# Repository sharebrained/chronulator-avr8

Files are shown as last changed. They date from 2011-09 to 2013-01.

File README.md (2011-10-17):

chronulator-avr8
================

by ShareBrained Technology

The latest version of this repository can be found at:
<https://github.com/sharebrained/chronulator-avr8>

Description
===========

An analog panel meter clock implementation based on the
Atmel AVR8 microcontroller.

Time is displayed via two analog meters, one for hours
and one for minutes. The microcontroller keeps time via
a 32.768kHz crystal, and controls the meter needles
using pulse-width modulation of current sources.

The current sources are adjustable by variable
resistors, and the time is set by momentary buttons.

A simple set of commands are supported via the AVR8
serial port. Meter needles can be controlled directly
via commands, overriding the default time-based
control. The brightness of two LEDs can be controlled
by other commands.

Documentation
=============

See http://www.sharebrained.com/chronulator/ for
hardware documentation.

Requirements
============

Software
--------

* Arduino IDE (to program the Chronulator firmware)
* avrdude (to program the AVR8 bootloader)
* avr-gcc (to compile and link the bootloader)
* EAGLE 5.x (to edit the schematic or circuit board)

Hardware
--------

* A Chronulator or Chronulator-compatible device.
* A serial adaptor and/or an Atmel ISP programmer.

Usage
=====

Before compiling and uploading this code in the Arduino
IDE, please select "LilyPad Arduino w/ ATmega168" under
the "Tools->Board" menu.

Contact
=======

ShareBrained Technology, Inc.
<http://www.sharebrained.com/>

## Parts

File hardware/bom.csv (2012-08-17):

Ref Des | Description | Package | Manufacturer | Manufacturer Part | Supplier | Supplier Part | Qty
U1 | IC AVR MCU 16K 10MHZ 28DIP | 28-DIP | AVR | ATMEGA168V-10PU | Digi-Key | ATMEGA168V-10PU-ND | 1
R1,2,5,6,7 | RES 10K OHM 1/4W 5% CARBON FILM | Axial | Yageo | CFR-25JB-10K | Digi-Key | 10KQBK-ND | 5
R3,8 | RES 82K OHM 1/4W 5% CARBON FILM | Axial | Yageo | CFR-25JB-82K | Digi-Key | 82KQBK-ND | 2
R4,9 | POT 5K OHM 9MM HORZ NO BUSHING | 9mm | Panasonic | EVU-E3AF25B53 | Digi-Key | P3M3502-ND | 2
Q1,2,3,4 | IC TRANS PNP SS GP 200MA | TO-92 | Fairchild | 2N3906BU | Digi-Key | 2N3906FS-ND | 4
C1,2 | CAP 18PF 50V CERAMIC C0G 5% | Radial, 5.08mm, orange | Vishay/BC | K180J15C0GF5TH5 | Digi-Key | BC1033CT-ND | 2
C3,4,6 | CAP CER 100000PF 50V Y5V | Radial, 5.0mm blue | Murata | RPEF51H104Z2K1A03B | Digi-Key | 490-3859-ND | 3
C5 | CAP CER 10UF 10V Y5V RAD | Radial, 5.0mm, blue, short leads | TDK | FK24Y5V1A106Z | Digi-Key | 445-2868-ND | 1
S1,2,3 | SWITCH TACT 6MM SPST PCB H=7.3MM | 6mm | ITT/C&K | PTS645SJL73 LFS | Digi-Key | CKN9072-ND | 3
X1 | CRYSTAL 32.768KHZ 12.5PF CYL | Abracon | AB38T-32.768KHZ | Digi-Key | 535-9034-ND | 1
 | HOLDER BATT 2-AA CELLS WIRE LDS | 2xAA | MPD | BC22AAW | Digi-Key | BC22AAW-ND | 1
BAT | CONN PWR JACK RT ANG 1.3MM I.D. |  | CUI | PJ-007 | Digi-Key | CP-2519-ND | 1
 | CONN POWER PLUG 3.5MM X 1.3MM |  | CUI | PP3-002D | Digi-Key | CP3-1003-ND | 1
H,M | 100uA panel meter |  | GME | PM89 100uA | GME | PM89-D100UA | 2
 | PCB |  | Advanced Circuits |  |  | pm2v-2.01 | 1
BAT/USB | CONN HEADER 50POS .100" SGL GOLD |  | Samtec | TSW-150-07-L-S | Digi-Key | SAM1031-50-ND
JUMPER | CONN JUMPER SHORTING GOLD FLASH |  | Sullins | SPC02SYAN | Digi-Key | S9001-ND | 1
SERIAL | CONN HDR 50POS .100" SNGL R/A |  | Samtec | TSW-150-08-T-S-RA | Digi-Key | SAM1051-50-ND
R10,11 | RES 0 OHM 1/4W 5% CARBON FILM | Axial | Stackpole | CD 1/4 0 R | Digi-Key | CD1/40RCT-ND | 2
D1,2,3,4,5 | LED 5MM COOL WHITE CLEAR 110DEG | Radial | Cree | C535A-WJN-CU0V0231 | Digi-Key | C535A-WJN-CU0V0231-ND | 2
ISP | CONN HDR BRKWAY .100 80POS VERT |  | Tyco | 4-103777-0 | Digi-Key | A26525-40-ND

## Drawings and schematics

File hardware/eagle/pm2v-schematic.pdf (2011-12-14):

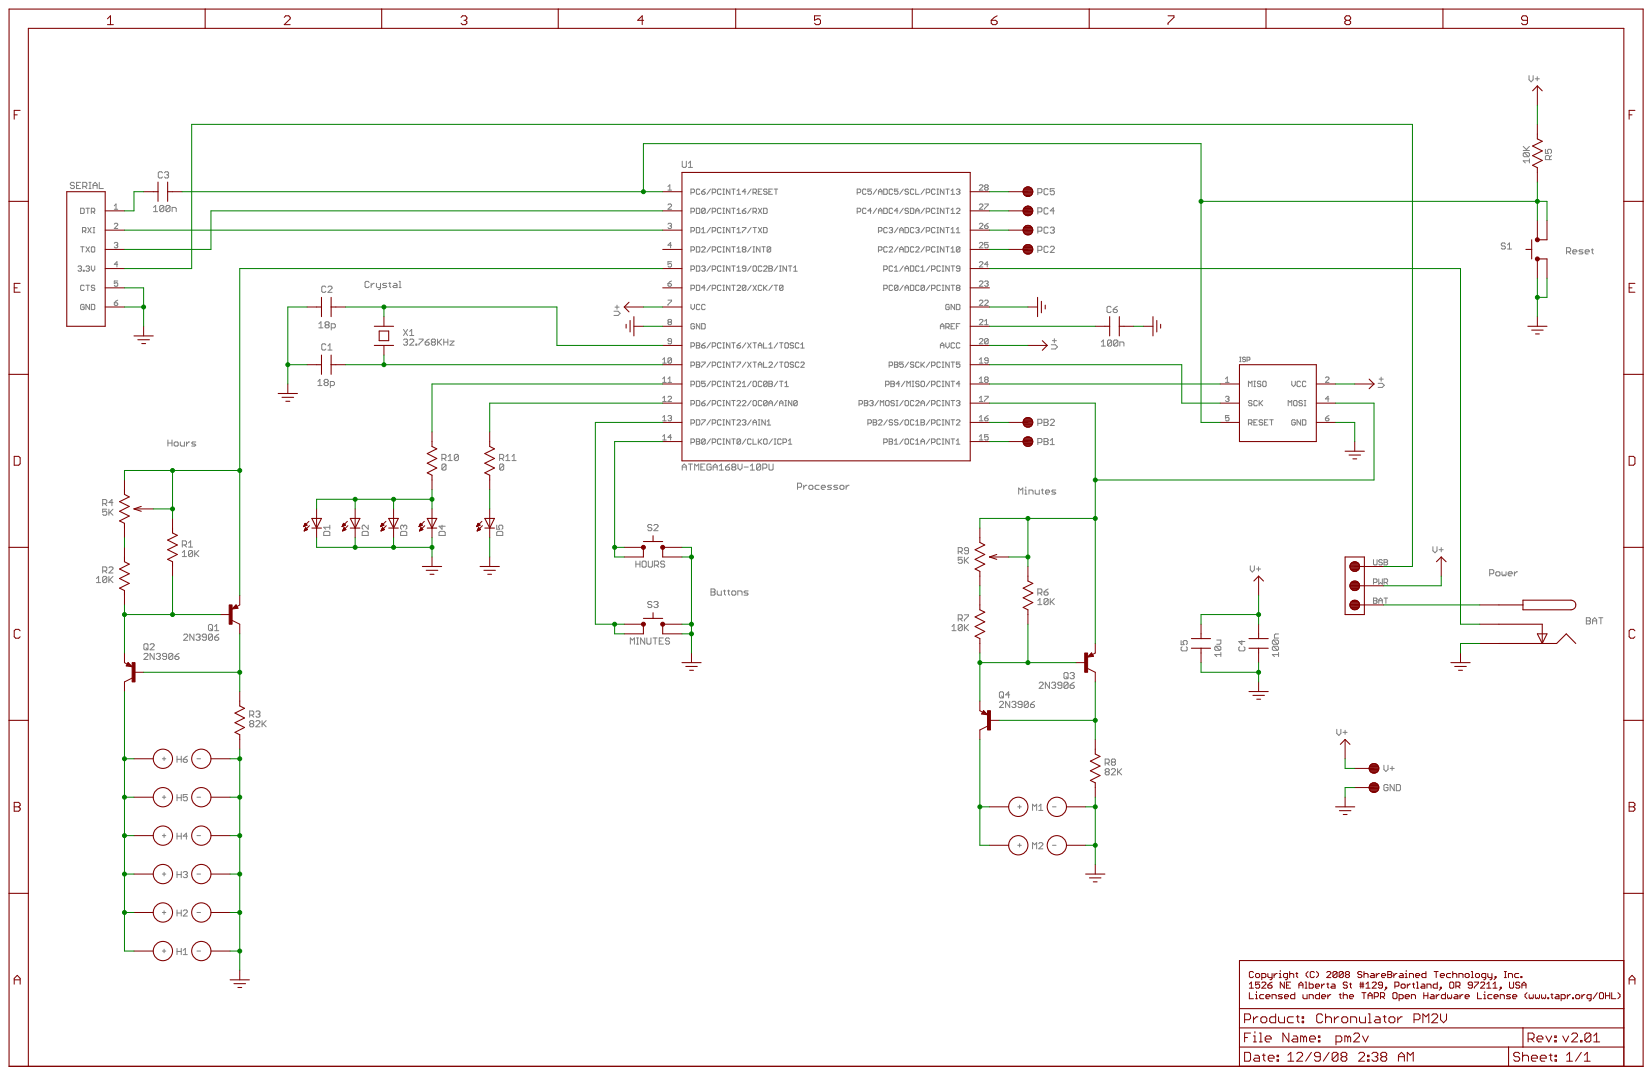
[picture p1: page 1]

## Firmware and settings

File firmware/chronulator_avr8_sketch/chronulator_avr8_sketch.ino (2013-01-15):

/*
 **********************************************************
 *
 * Copyright 2008-2013 ShareBrained Technology, Inc.
 *
 * This file is part of chronulator-avr8.
 *
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
 **********************************************************
 */

#include <avr/sleep.h>
#include <avr/power.h>
#include <util/delay.h>

#include "chronulator_types.h"

#define VERSION_RELEASE "201301151246-alpha"
#define F_CPU 4000000

static const unsigned short update_tick_interval = (1 << 4);

static const unsigned short servo_cycle_time = 20000;

static const unsigned short servo_center_minutes = 1500;
static const unsigned short servo_center_hours = 1500;

static const unsigned short servo_range_minutes = 900;
static const unsigned short servo_range_hours = 900;

static const unsigned char servo_h_power_timeout = 128 / update_tick_interval;
static const unsigned char servo_m_power_timeout = 128 / update_tick_interval;

static const unsigned char debounce_wait = 8;

#define HOURS_BUTTON_PIN (PINB)
#define HOURS_BUTTON_PIN_BIT (_BV(PINB0))
#define HOURS_BUTTON_PORT (PORTB)
#define HOURS_BUTTON_PORT_BIT (_BV(PORTB0))
#define HOURS_BUTTON_DDR (DDRB)
#define HOURS_BUTTON_DDR_BIT (_BV(DDB0))

#define MINUTES_BUTTON_PIN (PIND)
#define MINUTES_BUTTON_PIN_BIT (_BV(PIND7))
#define MINUTES_BUTTON_PORT (PORTD)
#define MINUTES_BUTTON_PORT_BIT (_BV(PORTD7))
#define MINUTES_BUTTON_DDR (DDRD)
#define MINUTES_BUTTON_DDR_BIT (_BV(DDD7))

#define METER_M_OCR (OCR2A)
#define METER_M_DDR (DDRB)
#define METER_M_DDR_BIT (_BV(DDB3))

#define METER_H_OCR (OCR2B)
#define METER_H_DDR (DDRD)
#define METER_H_DDR_BIT (_BV(DDD3))

#define METER_S_OCR (OCR0A)
#define METER_S_DDR (DDRD)
#define METER_S_DDR_BIT (_BV(DDD6))

#define METER_MS_OCR (OCR0B)
#define METER_MS_DDR (DDRD)
#define METER_MS_DDR_BIT (_BV(DDD5))

#define SERVO_M_OCR (OCR1A)
#define SERVO_M_DDR (DDRB)
#define SERVO_M_DDR_BIT (_BV(DDB1))

#define SERVO_H_OCR (OCR1B)
#define SERVO_H_DDR (DDRB)
#define SERVO_H_DDR_BIT (_BV(DDB2))

#define SERVO_M_POWER_PORT (PORTC)
#define SERVO_M_POWER_PORT_BIT (_BV(PORTC2))
#define SERVO_M_POWER_DDR (DDRC)
#define SERVO_M_POWER_DDR_BIT (_BV(DDC2))

#define SERVO_H_POWER_PORT (PORTC)
#define SERVO_H_POWER_PORT_BIT (_BV(PORTC3))
#define SERVO_H_POWER_DDR (DDRC)
#define SERVO_H_POWER_DDR_BIT (_BV(DDC3))

#define HOUR_PULSE_PORT (PORTD)
#define HOUR_PULSE_PORT_BIT (_BV(PORTD4))
#define HOUR_PULSE_DDR (DDRD)
#define HOUR_PULSE_DDR_BIT (_BV(DDD4))

#define MINUTE_PULSE_PORT (PORTD)
#define MINUTE_PULSE_PORT_BIT (_BV(PORTD2))
#define MINUTE_PULSE_DDR (DDRD)
#define MINUTE_PULSE_DDR_BIT (_BV(DDD2))

#define POWER_MODE_PIN (PINC)
#define POWER_MODE_PIN_BIT (_BV(PINC1))
#define POWER_MODE_PORT (PORTC)
#define POWER_MODE_PORT_BIT (_BV(PORTC1))
#define POWER_MODE_DDR (DDRC)
#define POWER_MODE_DDR_BIT (_BV(DDC1))

static meter_mode_t meter_mode = METER_MODE_SHOW_TIME;

class Time {
public:
    Time() :
        hour_(maximumHours / 2),
        minute_(minutesPerHour / 2),
        second_(0),
        tick_(0) {
    }

    void set_hour(unsigned char new_value) {
        hour_ = new_value;
    }

    unsigned char get_hour() const {
        return hour_;
    }

    void set_minute(unsigned char new_value) {
        minute_ = new_value;
    }

    unsigned char get_minute() const {
        return minute_;
    }

    void set_second(unsigned char new_value) {
        second_ = new_value;
    }

    unsigned char get_second() const {
        return second_;
    }

    void set_tick(unsigned char new_value) {
        tick_ = new_value;
    }

    unsigned char get_tick() const {
        return tick_;
    }

    void add_hour() {
        if( get_hour() < (maximumHours - 1) ) {
            set_hour(get_hour() + 1);
        } else {
            set_hour(0);
        }
    }

    void subtract_hour() {
        if( get_hour() > 0 ) {
            set_hour(get_hour() - 1);
        } else {
            set_hour(maximumHours - 1);
        }
    }

    void add_minute() {
        if( get_minute() < (minutesPerHour - 1) ) {
            set_minute(get_minute() + 1);
        } else {
            set_minute(0);
        }
    }

    void subtract_minute() {
        if( get_minute() > 0 ) {
            set_minute(get_minute() - 1);
        } else {
            set_minute(minutesPerHour - 1);
        }
    }

    void tick() {
        advance_tick();
    }

    static const unsigned char ticksPerSecond = 128;
    static const unsigned char secondsPerMinute = 60;
    static const unsigned char minutesPerHour = 60;
    static const unsigned char maximumHours = 12;

private:
    unsigned char hour_;
    unsigned char minute_;
    unsigned char second_;
    unsigned char tick_;

    void advance_hour() {
        add_hour();
    }

    void advance_minute() {
        add_minute();
        if( get_minute() == 0 ) {
            advance_hour();
        }
    }

    void advance_second() {
        add_second();
        if( get_second() == 0 ) {
            advance_minute();
        }
    }

    void advance_tick() {
        add_tick();
        if( get_tick() == 0 ) {
            advance_second();
        }
    }

    void add_second() {
        if( get_second() < (secondsPerMinute - 1) ) {
            set_second(get_second() + 1);
        } else {
            set_second(0);
        }
    }

    void add_tick() {
        if( get_tick() < (ticksPerSecond - 1) ) {
            set_tick(get_tick() + 1);
        } else {
            set_tick(0);
        }
    }
};

void set_start_of_hour(const bool value) {
    if( value ) {
        HOUR_PULSE_PORT |= HOUR_PULSE_PORT_BIT;
    } else {
        HOUR_PULSE_PORT &= ~HOUR_PULSE_PORT_BIT;
    }
}

void set_start_of_minute(const bool value) {
    if( value ) {
        MINUTE_PULSE_PORT |= MINUTE_PULSE_PORT_BIT;
    } else {
        MINUTE_PULSE_PORT &= ~MINUTE_PULSE_PORT_BIT;
    }
}

void enable_pulse_outputs() {
    set_start_of_hour(false);
    set_start_of_minute(false);
    HOUR_PULSE_DDR   |= HOUR_PULSE_DDR_BIT;
    MINUTE_PULSE_DDR |= MINUTE_PULSE_DDR_BIT;
}

static const unsigned short servo_offset_minutes = servo_center_minutes - (servo_range_minutes / 2);
static const unsigned short servo_offset_hours = servo_center_hours - (servo_range_hours / 2);

static const unsigned short servo_scale_minutes = servo_range_minutes / (Time::minutesPerHour - 1);
static const unsigned short servo_scale_hours = servo_range_hours / (Time::maximumHours - 1);

unsigned short meter_m_value(unsigned char minute) {
    // 0-60 mapped to 0-255
    return (minute * 4) + (minute / 4);
}

unsigned short meter_h_value(unsigned char hour) {
    // 0-12 mapped to 0-255
    return (hour * 21) + (hour / 4);
}

unsigned short meter_s_value(unsigned char second) {
    // 0-60 mapped to 0-255
    return (second * 4) + (second / 4);
}

unsigned short meter_ms_value(unsigned char tick) {
    // 0-128 mapped to 0-255
    if( tick > 127 ) {
        return 255;
    } else {
        return tick * 2;
    }
}

unsigned short servo_h_value(unsigned char hour) {
    return servo_offset_hours + hour * servo_scale_hours;
}

unsigned short servo_m_value(unsigned char minute) {
    return servo_offset_minutes + minute * servo_scale_minutes;
}

static Time time;

static unsigned char servo_h_power_counter = 0;

void enable_servo_h_power() {
    servo_h_power_counter = 0;
    SERVO_H_POWER_PORT |= SERVO_H_POWER_PORT_BIT;
}

void disable_servo_h_power() {
    SERVO_H_POWER_PORT &= ~SERVO_H_POWER_PORT_BIT;
}

void update_servo_h_power() {
    if( servo_h_power_counter < servo_h_power_timeout ) {
        servo_h_power_counter += 1;
    } else {
        disable_servo_h_power();
    }
}

static unsigned char servo_m_power_counter = 0;

void enable_servo_m_power() {
    servo_m_power_counter = 0;
    SERVO_M_POWER_PORT |= SERVO_M_POWER_PORT_BIT;
}

void disable_servo_m_power() {
    SERVO_M_POWER_PORT &= ~SERVO_M_POWER_PORT_BIT;
}

void update_servo_m_power() {
    if( servo_m_power_counter < servo_m_power_timeout ) {
        servo_m_power_counter += 1;
    } else {
        disable_servo_m_power();
    }
}

void update_servos_power() {
    update_servo_h_power();
    update_servo_m_power();
}

void set_hour_indicators(const unsigned char hour) {
    static unsigned char last_value = 255;
    if( hour != last_value ) {
        last_value = hour;
        METER_H_OCR = meter_h_value(hour);
        SERVO_H_OCR = servo_h_value(hour);
        enable_servo_h_power();
    }
}

void set_minute_indicators(const unsigned char minute) {
    static unsigned char last_value = 255;
    if( minute != last_value ) {
        last_value = minute;
        METER_M_OCR = meter_m_value(minute);
        SERVO_M_OCR = servo_m_value(minute);
        enable_servo_m_power();
    }
}

void set_second_indicators(const unsigned char second) {
    static unsigned char last_value = 255;
    if( second != last_value ) {
        last_value = second;
        METER_S_OCR = meter_s_value(second);
    }
}

void set_tick_indicators(const unsigned char tick) {
    // No need to track last value -- this value will probably
    // ALWAYS change, so we'll always update it, regardless.
    METER_MS_OCR = meter_ms_value(tick);
}

void update_cuckoo_signals() {
    if( time.get_second() == 0 ) {
        set_start_of_minute(true);
        if( time.get_minute() == 0 ) {
            set_start_of_hour(true);
        } else {
            set_start_of_hour(false);
        }
    } else {
        set_start_of_minute(false);
        set_start_of_hour(false);
    }
}

void update() {
    unsigned char hour, minute, second, tick;

    switch( meter_mode ) {
    default:
    case METER_MODE_SHOW_TIME:
        hour = time.get_hour();
        minute = time.get_minute();
        second = time.get_second();
        tick = time.get_tick();
        break;

    case METER_MODE_CALIBRATE_ZERO_SCALE:
        hour = 0;
        minute = 0;
        second = 0;
        tick = 0;
        break;

    case METER_MODE_CALIBRATE_FULL_SCALE:
        hour = Time::maximumHours;
        minute = Time::minutesPerHour;
        second = Time::secondsPerMinute;
        tick = Time::ticksPerSecond;
        break;

    }

    set_hour_indicators(hour);
    set_minute_indicators(minute);
    set_second_indicators(second);
    set_tick_indicators(tick);

    update_cuckoo_signals();
    update_servos_power();
}

void set_mode_show_time() {
    meter_mode = METER_MODE_SHOW_TIME;
}

void set_mode_calibrate_zero_scale() {
    meter_mode = METER_MODE_CALIBRATE_ZERO_SCALE;
}

void set_mode_calibrate_full_scale() {
    meter_mode = METER_MODE_CALIBRATE_FULL_SCALE;
}

void hours_button_pressed() {
    if( meter_mode == METER_MODE_SHOW_TIME ) {
        time.add_hour();
    }
}

void minutes_button_pressed() {
    if( meter_mode == METER_MODE_SHOW_TIME ) {
        time.add_minute();
    }
}

void both_buttons_pressed() {
    switch( meter_mode ) {
    case METER_MODE_SHOW_TIME:
        set_mode_calibrate_zero_scale();
        break;

    case METER_MODE_CALIBRATE_ZERO_SCALE:
        set_mode_calibrate_full_scale();
        break;

    case METER_MODE_CALIBRATE_FULL_SCALE:
        set_mode_show_time();
        break;

    default:
        set_mode_show_time();
        break;
    }
}

bool is_hours_button_pressed() {
    return (HOURS_BUTTON_PIN & HOURS_BUTTON_PIN_BIT) ? false : true;
}

bool is_minutes_button_pressed() {
    return (MINUTES_BUTTON_PIN & MINUTES_BUTTON_PIN_BIT) ? false : true;
}

static unsigned char debounce_counter = 0;

static button_mode_t button_mode = BUTTON_MODE_NONE;

button_mode_t read_button_mode() {
    const int result =
          (is_hours_button_pressed()   ? BUTTON_MODE_HOURS   : 0)
        | (is_minutes_button_pressed() ? BUTTON_MODE_MINUTES : 0);
    return (button_mode_t)result;
}

void fire_button_event(const button_mode_t button_mode) {
    switch( button_mode ) {
    case BUTTON_MODE_HOURS:
        hours_button_pressed();
        break;

    case BUTTON_MODE_MINUTES:
        minutes_button_pressed();
        break;

    case BUTTON_MODE_BOTH:
        both_buttons_pressed();
        break;

    default:
        break;
    }
}

void debounce_buttons() {
    const button_mode_t button_mode_before = button_mode;
    const button_mode_t button_mode_now = read_button_mode();
    if( button_mode_now != button_mode ) {
        debounce_counter += 1;
        if( debounce_counter == debounce_wait ) {
            // Button mode is stable, allow it to change.
            button_mode = button_mode_now;
            if( button_mode_before == BUTTON_MODE_NONE ) {
                // fire an event if the prior state was "no buttons pressed".
                fire_button_event(button_mode);
            }
        }
    } else {
        debounce_counter = 0;
    }
}

bool sleepModeCausesSpuriousTimer2Interrupts() {
    switch( SMCR & (_BV(SM2) | _BV(SM1) | _BV(SM0)) ) {
    case (_BV(SM1) | _BV(SM0)):
    case (_BV(SM0)):
        // Power-save or ADC Noise Reduction
        return true;

    default:
        return false;
    }
}

void waitForTimer2CycleToEnd() {
    while( ASSR & (_BV(TCN2UB)
                 | _BV(OCR2AUB) | _BV(OCR2BUB)
                 | _BV(TCR2AUB) | _BV(TCR2BUB)) );
}

void enable_timer0() {
    power_timer0_enable();

    TIMSK0 = 0;

    TCNT0 = 0;
    METER_S_OCR = 0;
    METER_MS_OCR = 0;

    TCCR0A = _BV(COM0A1) | _BV(COM0B1) /*| _BV(WGM01)*/| _BV(WGM00);
    TCCR0B = 0;

    TIFR0 = _BV(OCF0B) | _BV(OCF0A) | _BV(TOV0);
}

void enable_s_and_ms_meters() {
    enable_timer0();

    // TODO: PORTD settings?
    METER_S_DDR  |= METER_S_DDR_BIT;
    METER_MS_DDR |= METER_MS_DDR_BIT;
}

void enable_servos() {
    power_timer1_enable();

    TIMSK1 = 0;

    ICR1 = servo_cycle_time;
    TCNT1 = 0;
    SERVO_M_OCR = 0;
    SERVO_H_OCR = 0;

    TCCR1A = _BV(COM1A1) | _BV(COM1B1) | _BV(WGM11);
    TCCR1B = _BV(WGM13) | _BV(WGM12);

    TIFR1 = _BV(ICF1) | _BV(OCF1B) | _BV(OCF1A) | _BV(TOV1);

    SERVO_M_DDR |= SERVO_M_DDR_BIT;
    SERVO_M_POWER_DDR |= SERVO_M_POWER_DDR_BIT;

    SERVO_H_DDR |= SERVO_H_DDR_BIT;
    SERVO_H_POWER_DDR |= SERVO_H_POWER_DDR_BIT;
}

static PowerMode power_mode = POWER_MODE_LOW_POWER;

void initialize_high_power_mode() {
    power_mode = POWER_MODE_HIGH_POWER;

    // Clock is internal RC at 8MHz, assuming operation from a voltage
    // supply >= 2.5V. (See data sheet section 29.3 "Speed Grades".)
    clock_prescale_set(clock_div_1);

    enable_s_and_ms_meters();
    enable_servos();

    // Use idle sleep mode, which allows all the peripherals to continue
    // operating during sleep. This is what enables lots of cool features
    // at the expensive of high power consumption -- too high to run from
    // batteries for a decent amount of time.
    set_sleep_mode(SLEEP_MODE_IDLE);
}

void initialize_low_power_mode() {
    power_mode = POWER_MODE_LOW_POWER;

    // Clock is internal RC at 8MHz, scaled to 4MHz to stay within
    // clock rate limitations for voltage supply < 2.5V.
    // (See data sheet section 29.3 "Speed Grades".)
    clock_prescale_set(clock_div_2);

    // Use power-save mode mode, which shuts down all sections of the AVR
    // except for the asynchronous clock (the 32.768kHz crystal), timer 2
    // (which is driving the hours/minutes meters), and a few other
    // uninteresting peripherals.
    set_sleep_mode(SLEEP_MODE_PWR_SAVE);
}

void set_power_mode() {
    if( (POWER_MODE_PIN & POWER_MODE_PIN_BIT) == 0 ) {
        initialize_high_power_mode();
    } else {
        initialize_low_power_mode();
    }
}

ISR(TIMER2_OVF_vect) {
    // Ensure TOSC cycle will not cause extra interrupts.
    // a. Write a value to TCCR2x, TCNT2, or OCR2x.
    // Steps b, c happen immediately before sleep.
    TCCR2B = _BV(CS20);

    time.tick();
}

void enable_power_mode_input() {
    // Make pin input.
    POWER_MODE_DDR &= ~POWER_MODE_DDR_BIT;

    // Enable pull-up on pin.
    POWER_MODE_PORT |= POWER_MODE_PORT_BIT;
}

void enable_switch_inputs() {
    // Make pins inputs.
    HOURS_BUTTON_DDR   &= ~HOURS_BUTTON_DDR_BIT;
    MINUTES_BUTTON_DDR &= ~MINUTES_BUTTON_DDR_BIT;

    // Enable pull-ups on pins.
    HOURS_BUTTON_PORT   |= HOURS_BUTTON_PORT_BIT;
    MINUTES_BUTTON_PORT |= MINUTES_BUTTON_PORT_BIT;
}

void initializePorts() {
    // Configure I/O pins for lowest power.

    // PB0: I, pullup: Switch (DDB0=0, PB0=1)
    // PB1: O: OC1A PWM output (DDB1=1, PB1=0)
    // PB2: O: OC1B PWM output (DDB2=1, PB2=0)
    // PB3: O: OC2A PWM output, "minutes" meter (DDB3=1, PB3=0)
    // PB4: I:
    // PB5: I:
    // PB6: I: TOSC1 (crystal) (DDB6=0, PB6=0)
    // PB7: I: TOSC2 (crystal) (DDB7=0, PB7=0)
    DDRB = 0;
    PORTB = 0;

    // PC0: I:
    // PC1: I, pullup: DC plug present (DDC1=0, PC1=1)
    // PC2: O: Servo M power (DDC2=1, PC2=0)
    // PC3: O: Servo H power (DDC3=1, PC3=0)
    // PC4: I:
    // PC5: I:
    // PC6: I: RESET
    // PC7: I: (no pin)
    DDRC = 0;
    PORTC = 0;

    // PD0: I: RXD Serial RX (DDD0=0, PD0=1)
    // PD1: O: TXD Serial TX (DDD1=1, PD1=1)
    // PD2: I: Start-of-minute pulse (DDD2=1, PD2=0)
    // PD3: O: OC2B PWM output, "hours" meter (DDD3=1, PD3=0)
    // PD4: I: Start-of-hour pulse (DDD4=1, PD4=0)
    // PD5: O: OC0B PWM output, LED (DDD5=1, PD5=0)
    // PD6: O: OC0A PWM output, LED (DDD6=1, PD6=0)
    // PD7: I, pullup: Switch (DDD7=0, PD7=1)
    DDRD = 0;
    PORTD = 0;

    // Do not disable internal pull-up resistors on ports.
    MCUCR &= ~_BV(PUD);

    enable_power_mode_input();
    enable_switch_inputs();
    enable_pulse_outputs();
}

void initializeAnalogToMinimizePower() {
    // Turning off analog stuff saves 120uA:
    ACSR |= _BV(ACD); // Disable analog comparator.
    //ACSR &= ~_BV(ACBG);	// Select analog input as reference (instead of bandgap).
    //DIDR1 = _BV(AIN1D) | _BV(AIN0D); // Disable digital input buffers on analog inputs.
    ADMUX &= ~(_BV(REFS1) | _BV(REFS0)); // Turn off AREF, internal Vref.
    ADCSRA &= ~_BV(ADEN); // Disable ADC.
}

void initializeTimer2For32KHzCrystal() {
    power_timer2_enable();

    // Timer 2 async setup (section 17.9)
    // a. Disable the Timer/Counter2 interrupts by clearing OCIE2x and TOIE2.
    TIMSK2 = 0;

    // b. Select clock source by setting AS2 as appropriate.
    ASSR = _BV(AS2);

    // b(2). Wait for clock to come up.
    _delay_ms(1000);

    // c. Write new values to TCNT2, OCR2x, and TCCR2x.
    TCNT2 = 0;
    METER_M_OCR = 0;
    METER_H_OCR = 0;

    TCCR2A = _BV(COM2A1) | _BV(COM2B1) | _BV(WGM21) | _BV(WGM20);
    TCCR2B = 0;

    // d. To switch to asynchronous operation: Wait for TCN2xUB, OCR2xUB, and TCR2xUB.
    while( ASSR & (_BV(TCN2UB)
                 | _BV(OCR2AUB) | _BV(OCR2BUB)
                 | _BV(TCR2AUB) | _BV(TCR2BUB)) );

    // e. Clear the Timer/Counter2 Interrupt Flags.
    TIFR2 = _BV(OCF2B) | _BV(OCF2A) | _BV(TOV2);

    // f. Enable interrupts, if needed.
    TIMSK2 = _BV(TOIE2);

    METER_M_DDR |= METER_M_DDR_BIT;
    METER_H_DDR |= METER_H_DDR_BIT;
}

void setup() {
    clock_prescale_set(clock_div_2);

    cli();

    initializePorts();

    initializeAnalogToMinimizePower();

    power_all_disable();

    initializeTimer2For32KHzCrystal();

    set_power_mode();

    sei();

    // Start timers.
    TCCR0B |= _BV(CS01) | _BV(CS00); // timer 0 operates at clkio/64
    TCCR1B |= _BV(CS11);             // timer 1 operates at clkio/8
    TCCR2B |= _BV(CS20);             // timer 2 operates at clkt2s/1
}

void loop() {
    // Can't re-enter power save mode until the TOSC1 cycle that woke us is
    // complete. Write to certain timer 2 registers (TCNT2, TCCR2x, or OCR2x)
    // to start an operation that completes with TOSC1 in the right state.
    // Completion is indicated by the appropriate busy flag in the ASSR
    // register.
    waitForTimer2CycleToEnd();

    sleep_mode();

    // Timer 2 interrupt will wake the AVR from the above sleep.
    // The interrupt will execute and return, then this code will
    // be executed.

    debounce_buttons();

    // Update the meters and servos every 8th of a second, plenty
    // often for how fast meters and servos can actually react.
    if( (time.get_tick() & (update_tick_interval - 1)) == 0 ) {
        update();
    }
}

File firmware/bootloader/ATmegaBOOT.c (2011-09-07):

/**********************************************************/
/* Serial Bootloader for Atmel megaAVR Controllers        */
/*                                                        */
/* tested with ATmega8, ATmega128 and ATmega168           */
/* should work with other mega's, see code for details    */
/*                                                        */
/* ATmegaBOOT.c                                           */
/*                                                        */
/* 20070626: hacked for Arduino Diecimila (which auto-    */
/*           resets when a USB connection is made to it)  */
/*           by D. Mellis                                 */
/* 20060802: hacked for Arduino by D. Cuartielles         */
/*           based on a previous hack by D. Mellis        */
/*           and D. Cuartielles                           */
/*                                                        */
/* Monitor and debug functions were added to the original */
/* code by Dr. Erik Lins, chip45.com. (See below)         */
/*                                                        */
/* Thanks to Karl Pitrich for fixing a bootloader pin     */
/* problem and more informative LED blinking!             */
/*                                                        */
/* For the latest version see:                            */
/* http://www.chip45.com/                                 */
/*                                                        */
/* ------------------------------------------------------ */
/*                                                        */
/* based on stk500boot.c                                  */
/* Copyright (c) 2003, Jason P. Kyle                      */
/* All rights reserved.                                   */
/* see avr1.org for original file and information         */
/*                                                        */
/* This program is free software; you can redistribute it */
/* and/or modify it under the terms of the GNU General    */
/* Public License as published by the Free Software       */
/* Foundation; either version 2 of the License, or        */
/* (at your option) any later version.                    */
/*                                                        */
/* This program is distributed in the hope that it will   */
/* be useful, but WITHOUT ANY WARRANTY; without even the  */
/* implied warranty of MERCHANTABILITY or FITNESS FOR A   */
/* PARTICULAR PURPOSE.  See the GNU General Public        */
/* License for more details.                              */
/*                                                        */
/* You should have received a copy of the GNU General     */
/* Public License along with this program; if not, write  */
/* to the Free Software Foundation, Inc.,                 */
/* 59 Temple Place, Suite 330, Boston, MA  02111-1307 USA */
/*                                                        */
/* Licence can be viewed at                               */
/* http://www.fsf.org/licenses/gpl.txt                    */
/*                                                        */
/* Target = Atmel AVR m128,m64,m32,m16,m8,m162,m163,m169, */
/* m8515,m8535. ATmega161 has a very small boot block so  */
/* isn't supported.                                       */
/*                                                        */
/* Tested with m168                                       */
/**********************************************************/

/* $Id$ */


/* some includes */
#include <inttypes.h>
#include <avr/io.h>
#include <avr/pgmspace.h>
#include <avr/interrupt.h>
#include <avr/wdt.h>


/* the current avr-libc eeprom functions do not support the ATmega168 */
/* own eeprom write/read functions are used instead */
#ifndef __AVR_ATmega168__
#include <avr/eeprom.h>
#endif

/* Use the F_CPU defined in Makefile */

/* 20060803: hacked by DojoCorp */
/* 20070626: hacked by David A. Mellis to decrease waiting time for auto-reset */
/* set the waiting time for the bootloader */
/* get this from the Makefile instead */
/* #define MAX_TIME_COUNT (F_CPU>>4) */

/* 20070707: hacked by David A. Mellis - after this many errors give up and launch application */
#define MAX_ERROR_COUNT 5

/* set the UART baud rate */
/* 20060803: hacked by DojoCorp */
//#define BAUD_RATE   115200
#define BAUD_RATE   19200


/* SW_MAJOR and MINOR needs to be updated from time to time to avoid warning message from AVR Studio */
/* never allow AVR Studio to do an update !!!! */
#define HW_VER	 0x02
#define SW_MAJOR 0x01
#define SW_MINOR 0x10


/* Adjust to suit whatever pin your hardware uses to enter the bootloader */
/* ATmega128 has two UARTS so two pins are used to enter bootloader and select UART */
/* BL0... means UART0, BL1... means UART1 */
#ifdef __AVR_ATmega128__
#define BL_DDR  DDRF
#define BL_PORT PORTF
#define BL_PIN  PINF
#define BL0     PINF7
#define BL1     PINF6
#else
/* other ATmegas have only one UART, so only one pin is defined to enter bootloader */
#define BL_DDR  DDRD
#define BL_PORT PORTD
#define BL_PIN  PIND
#define BL      PIND6
#endif


/* onboard LED is used to indicate, that the bootloader was entered (3x flashing) */
/* if monitor functions are included, LED goes on after monitor was entered */
#ifdef __AVR_ATmega128__
/* Onboard LED is connected to pin PB7 (e.g. Crumb128, PROBOmega128, Savvy128) */
#define LED_DDR  DDRB
#define LED_PORT PORTB
#define LED_PIN  PINB
#define LED      PINB7
#else
/* Onboard LED is connected to pin PB2 (e.g. Crumb8, Crumb168) */
#define LED_DDR  DDRD
#define LED_PORT PORTD
#define LED_PIN  PIND
/* 20060803: hacked by DojoCorp, LED pin is B5 in Arduino */
/* #define LED      PINB2 */
#define LED_M    PIND6
#define LED_H    PIND5
#endif


/* monitor functions will only be compiled when using ATmega128, due to bootblock size constraints */
#ifdef __AVR_ATmega128__
#define MONITOR
#endif


/* define various device id's */
/* manufacturer byte is always the same */
#define SIG1	0x1E	// Yep, Atmel is the only manufacturer of AVR micros.  Single source :(

#if defined __AVR_ATmega128__
#define SIG2	0x97
#define SIG3	0x02
#define PAGE_SIZE	0x80U	//128 words

#elif defined __AVR_ATmega64__
#define SIG2	0x96
#define SIG3	0x02
#define PAGE_SIZE	0x80U	//128 words

#elif defined __AVR_ATmega32__
#define SIG2	0x95
#define SIG3	0x02
#define PAGE_SIZE	0x40U	//64 words

#elif defined __AVR_ATmega16__
#define SIG2	0x94
#define SIG3	0x03
#define PAGE_SIZE	0x40U	//64 words

#elif defined __AVR_ATmega8__
#define SIG2	0x93
#define SIG3	0x07
#define PAGE_SIZE	0x20U	//32 words

#elif defined __AVR_ATmega88__
#define SIG2	0x93
#define SIG3	0x0a
#define PAGE_SIZE	0x20U	//32 words

#elif defined __AVR_ATmega168__
#define SIG2	0x94
#define SIG3	0x06
#define PAGE_SIZE	0x40U	//64 words

#elif defined __AVR_ATmega162__
#define SIG2	0x94
#define SIG3	0x04
#define PAGE_SIZE	0x40U	//64 words

#elif defined __AVR_ATmega163__
#define SIG2	0x94
#define SIG3	0x02
#define PAGE_SIZE	0x40U	//64 words
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

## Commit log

2011-09-07 Custom boot loader (for startup with only a 32.768kHz crystal). Arduino sketch (C-style, no Arduino libraries used). EAGLE schematic, circuit board and design rules. Added license to relevant files. 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
    [pm2v.brd, pm2v.sch]
2011-09-07 Renamed Arduino sketch. Arduino apparently doesn't like sketches with hyphens in the file name?
2011-09-07 Added bill of materials.
    [bom.csv]
2011-09-28 Added a note to use the LilyPad ATmega168 board when compiling in Arduino IDE.
2011-09-28 Removed TODO: comment about renaming switches.
2011-09-28 Improved terminology: references to "battery" are now "DC jack", since it's not always a battery connected to the DC jack... It could be a power adapter.
2011-09-28 Change low/high power mode detect from using DC jack to monitoring state of pin PC0. If PC0 is grounded, enter high-power mode. Otherwise, run in low-power mode.
2011-09-28 Check power mode once at power-up -- no more dynamic switching, as it's a *very* unlikely use case.
2011-09-28 Removed the command processor. It was never properly documented, and I should be building off Arduino libraries, which have become pretty sophisticated at this point (e.g. CmdMessenger).
2011-09-28 Initial hours/minutes servo implementation using Timer 1 at 1us resolution, fast PWM mode with ICR1 as the TOP value. Seems to work pretty well...
2011-10-01 Simplify control of sleep mode. Power mode is determined only at power-on, so updating sleep mode when peripherals are enabled is unnecessary.
2011-10-02 Changed meter minute/hour scaling to support fractional scaling. This allows full 0-255 range for hours and minutes, and might improve calibration for people whose meters (or batteries?) are a bit "w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
2011-10-02 Added seconds and milliseconds meter support, replacing the LED PWM support. I figure if somebody wants LEDs, they can buy a BlinkM or similar. That'd be easier than trying to use the code I just rem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
2011-10-02 Removed a remaining case of variables named after switch reference designators: "_s1" becomes "_hours" and "_s2" becomes "_minutes".
2011-10-02 Removed code to power-down peripherals, since power mode is now set once at start-up and never changed. Removed related dead and useless code.
2011-10-02 Re-arranged power mode initialization code a bit. There's no longer a need to structure the high- and low-power code differently. And I added some lovely comments to explain what's going on and why.
2011-11-17 Change the way servo PWM values are computed, to correspond more with the actual meaning of the PWM signal. Factor out the servo cycle time into a constant.
2011-11-17 Move servo pulse configuration code to top of file, since it's something people will likely want to fiddle with.
2011-12-12 Update BOM -- gold stake pins (because that's how I roll) and change the crystal to one that's not discontinued.
    [bom.csv]
2011-12-14 Added schematic for Chronulator 2.01 design in PDF format for easy browsing.
2012-01-10 Shrunk servo PWM range a bit to keep servos from chattering at their limit.
2012-01-10 Cleaned up servo range arithmetic a bit to hit full-scale, instead of one step below full-scale.
2012-01-10 Simplified button debouncing. Debouncing now occurs against the combined (hours + minutes) button state. Events are only fired if new state is entered from the "no buttons pressed" state, which shoul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
2012-01-10 Move button debouncing and Timer 2 errata code out of interrupt. The button debouncing and handling code isn't terribly time-sensitive. The Timer 2 errata code just needs to run before sleep mode -- 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
2012-01-10 Removed Time callback machinery. Now updating meters, servos, and signals each pass through the loop(), instead of expending lots of effort tracking when a time value has changed.
2012-01-11 Simplified a couple of single-case switch() statements.
2012-01-11 Oops, in refactoring the button state code, I flipped the state -- the GPIO pins are active *low*.
2012-01-11 Increased debounce time to avoid changing hours or minutes value when pressing both buttons to enter calibration mode. This is a trade-off with making the time-setting mode of the buttons a bit lazy 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
2012-01-11 Restructured code (again!) to reduce power consumption. It was a bad idea to recalculate meter positions for *every* tick. It increased power consumption by 20% or 30%.
2012-01-11 Debounce timer was still too long for comfort, so I shortened it up a bit...
2012-01-13 Modified neutral servo position to 1500us to match documentation I've found about Hitec and Futaba servos.
2012-01-13 Adjusted servo range to match the limits of most servos -- deflection of +/- 45 degrees from neutral.
2012-01-13 Code to manage servo power using two GPIO pins. GPIO pins will go high when their corresponding servo needs to move, and will stay high for ~128 ticks (one second) to allow the servo to slew to the n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
2012-01-13 Change meter/servo update scheme to update every 8th of a second (32 / 128). Only update servos/meters if the values they're displaying have actually changed. The Time class no longer has to notify n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
2012-01-13 Removed update_[hour|minute|second|tick]_indicators() functions, and incorporated into a single switch() in a single function.
2012-01-31 Consolidate pin assignment #defines and constants at the top of the source file.
2012-01-31 Make better use of pin assignment #defines in setup code.
2012-01-31 Remove configuration code for now-unused "high-power mode select" pin. I've moved that function to the DC plug presence detect pin.
2012-01-31 Found bug where servo power pulses were too short, because the loop() function was executing too quickly. Moved servo power pulse update to a tick-controlled block of code. TODO: This probably means 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
2012-02-01 Clean up timer 2 interrupt handling. I was getting spurious interrupts when using idle power mode. So I'm using the wait-until-end-of-TOSC2-cycle code in all power modes now. I've also fixed timer 2 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
2012-02-01 Increased servo/meter update rate from 1/8 second to 1/16 second, to improve perceived responsiveness to switch presses.
2012-02-01 Corrected regression (due to an editor crash?) where I needed to watch ALL ASSR busy flags before considering the current TOSC cycle concluded.
2012-02-01 Clean up timer 0, timer 1 interrupt mask/flag initialization.
2012-02-01 Change timer 1 initialization sequence to match timer 2 (and official documentation).
2012-02-01 Corrected inaccurate comment about timer 2 TOSC1 synchronization process.
2012-02-01 Consolidate timer starts to post-initialization.
2012-02-01 Serious formatting clean-up. Arduino IDE made a mess of indentation, so now indents are four spaces -- no tabs.
2012-08-17 Substituted X1 from Epson with similar device from Abracon.
    [bom.csv]
2013-01-15 Rename Arduino sketch from .pde extension to .ino extension to match newer Arduino IDE expectations.
2013-01-15 Moved enum typedefs into a separate file to address changes in Arduino compilation order/behavior. Updated release date. Updated copyright date range.

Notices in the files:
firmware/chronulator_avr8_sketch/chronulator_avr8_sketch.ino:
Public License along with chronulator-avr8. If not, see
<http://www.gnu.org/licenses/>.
